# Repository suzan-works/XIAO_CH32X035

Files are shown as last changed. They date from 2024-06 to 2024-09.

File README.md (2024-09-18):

# サポートページ：CH32X035搭載XIAOピン互換ボード Support page for CH32X035 XIAO-Compatible Board #XIAO_CH32X035
WCH CH32X035を搭載した小型のマイコンボードです。
Arduino IDEからプログラム可能で、USB PDシンクとして動作できます。

Tiny microcontroller board equipped with WCH CH32X035. 
It can be programmed from the Arduino IDE and functions as a USB PD sink.  

## CH32X035搭載XIAOピン互換ボード CH32X035 XIAO-Compatible Board
WCH CH32X035搭載のUSB PD対応マイコンボードです。  
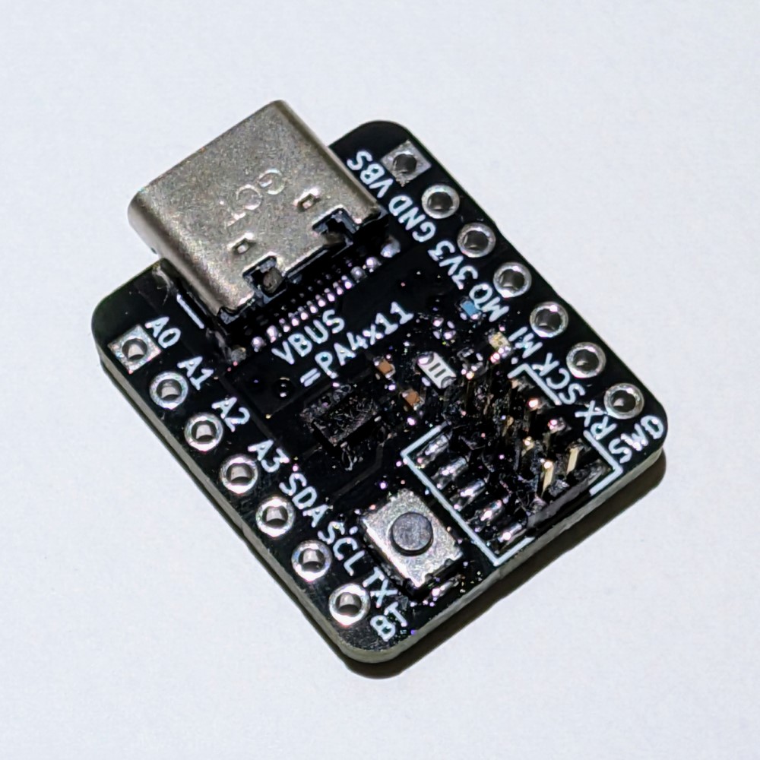
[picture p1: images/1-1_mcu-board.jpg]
  
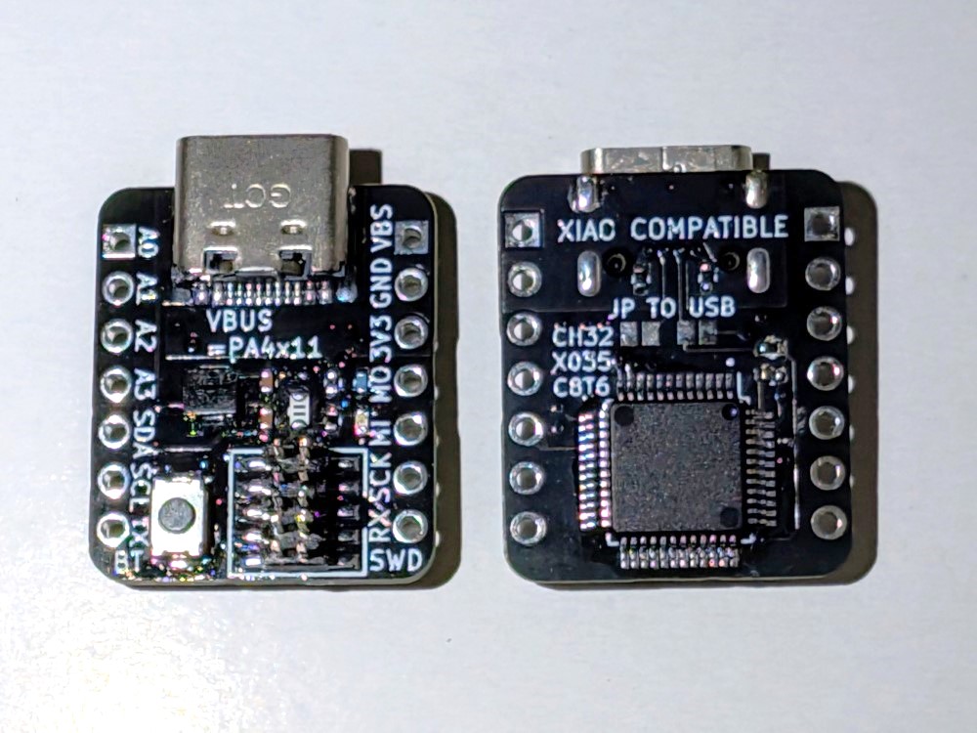
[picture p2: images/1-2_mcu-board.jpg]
  
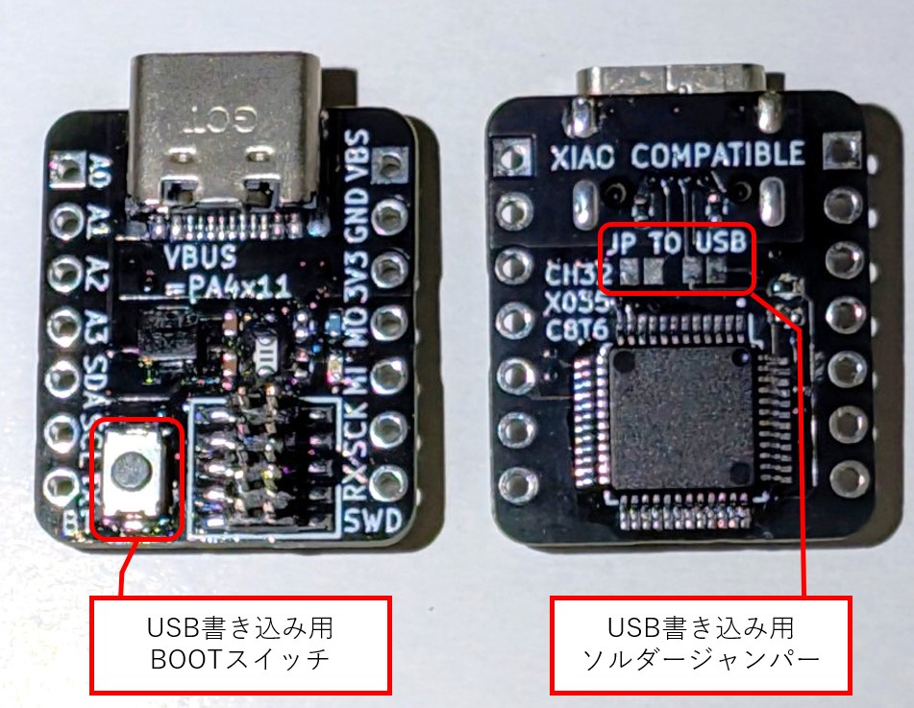
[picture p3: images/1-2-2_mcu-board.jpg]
  
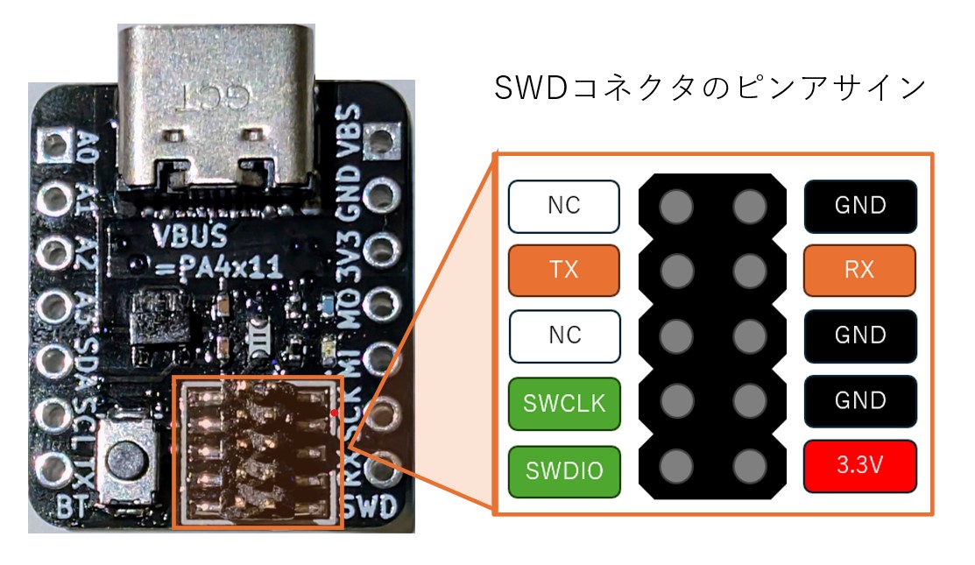
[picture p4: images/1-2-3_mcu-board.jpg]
  
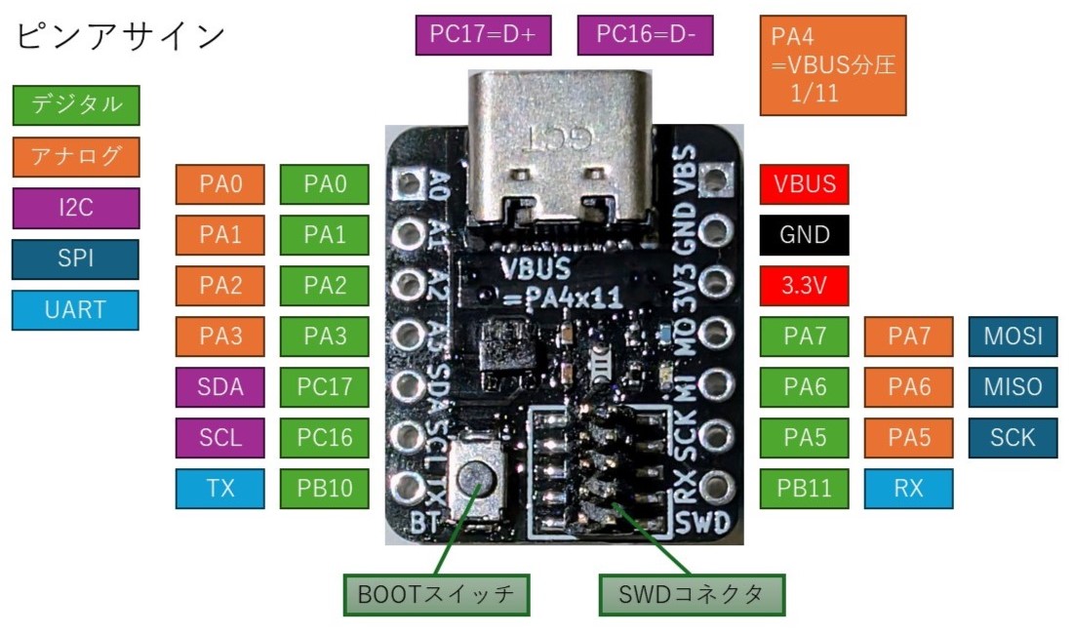
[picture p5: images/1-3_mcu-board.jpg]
  
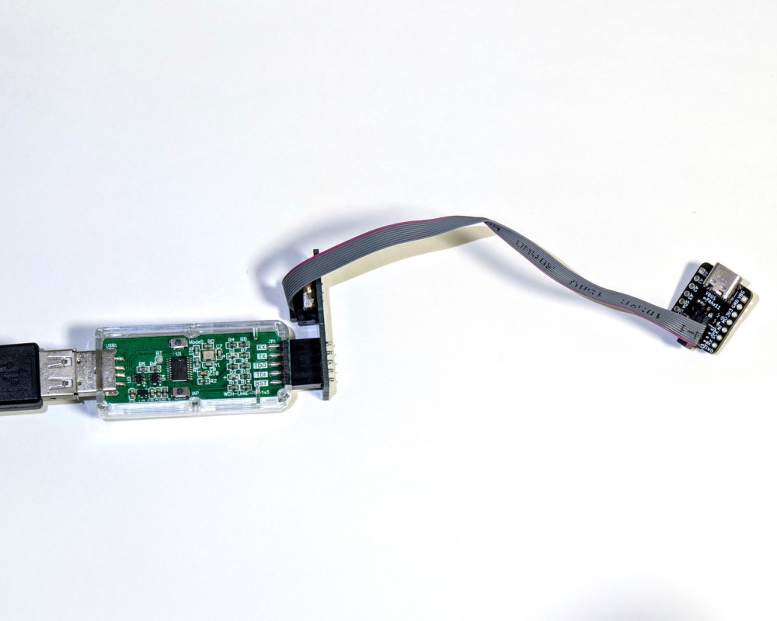
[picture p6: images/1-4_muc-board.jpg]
  
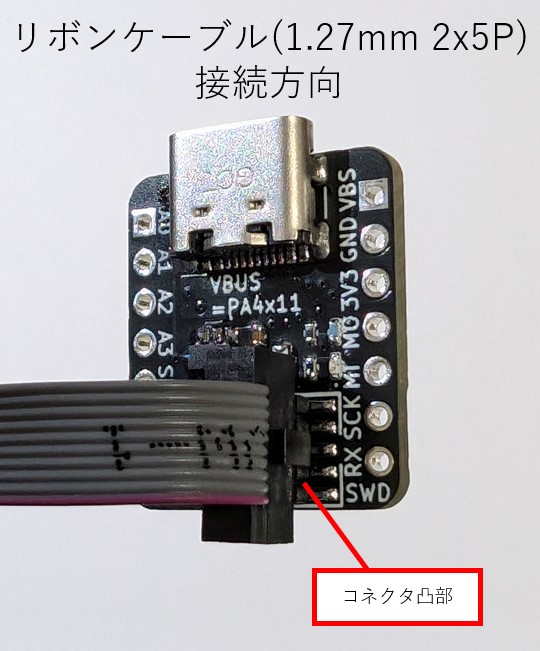
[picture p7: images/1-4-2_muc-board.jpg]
  
  
[回路図PDF](hardware/CH32X035_XIAO-Compatible_Board/CH32X035_XIAO-Compatible_Board.pdf)  
[回路図をブラウザで見る](https://kicanvas.org/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)  
[基板データをブラウザで見る](https://kicanvas.org/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)  
  
## SWD変換基板 SWD Converter Board
デバッガWCH-LinkEとマイコンボード上のコネクタ(1.27mm 10P)を接続するための変換基板です。  
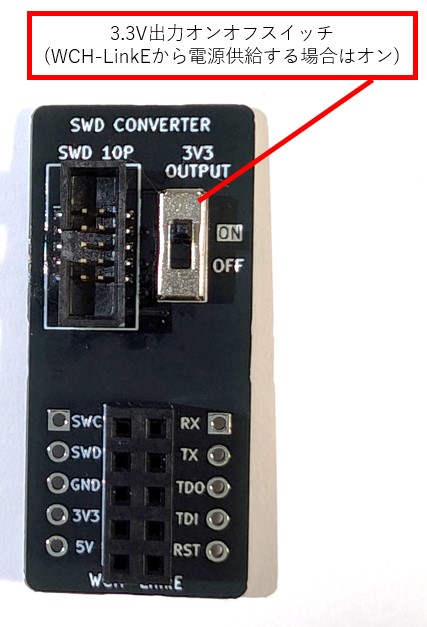
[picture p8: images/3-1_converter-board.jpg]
  
  
[回路図PDF](hardware/SWD_Converter_Board/SWD_Converter_Board.pdf)  
[回路図をブラウザで見る](https://kicanvas.org/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)  
[基板データをブラウザで見る](https://kicanvas.org/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)  
  
## VBUSスイッチアドオンボード VBUS Switch Add-on Board
マイコンボードからVBUS出力のオンオフを切り替えられるアドオンボードです。
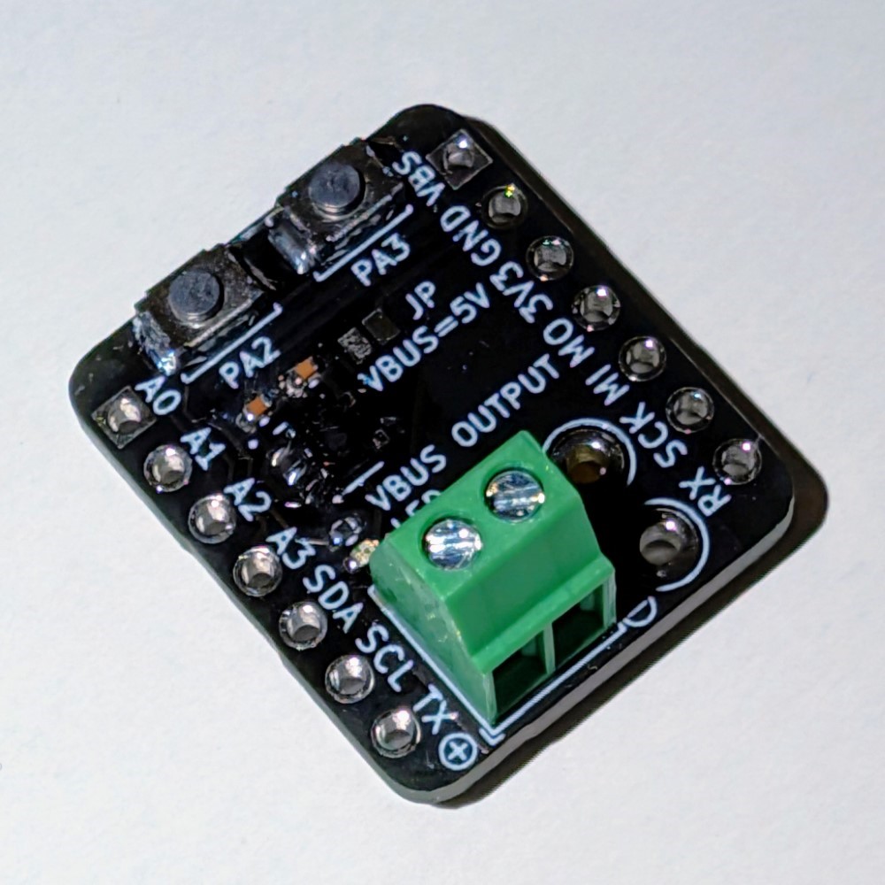
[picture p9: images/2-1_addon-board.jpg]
  
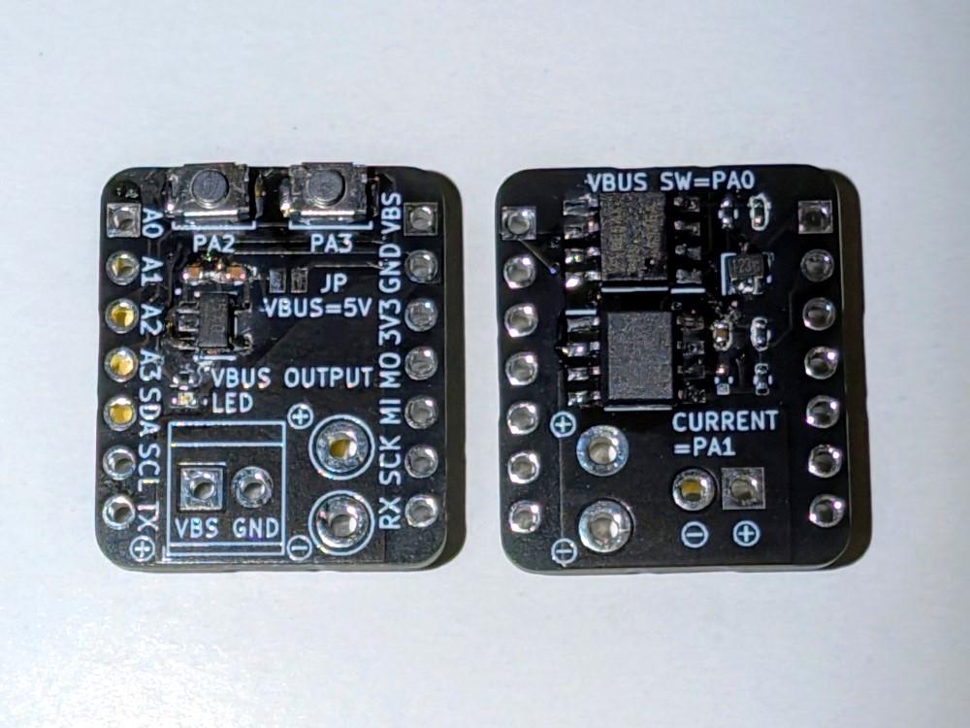
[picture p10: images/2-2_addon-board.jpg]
  
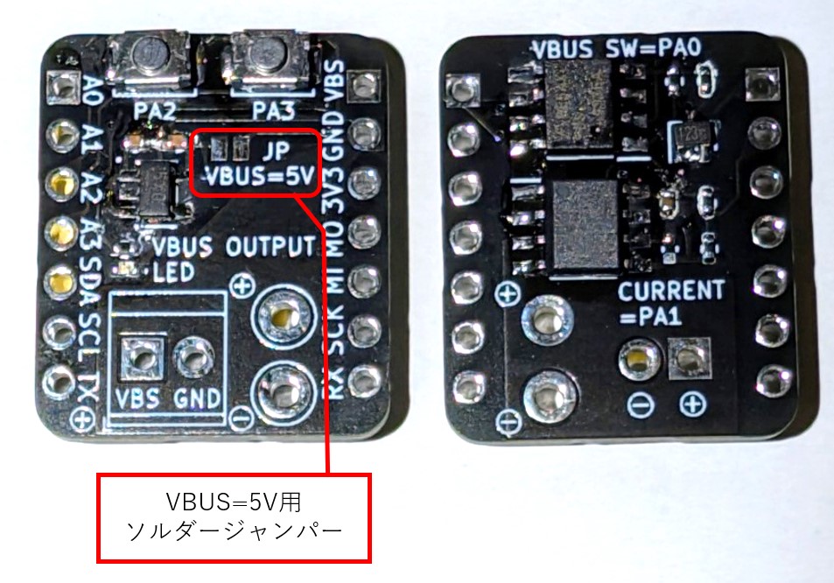
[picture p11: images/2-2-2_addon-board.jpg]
  
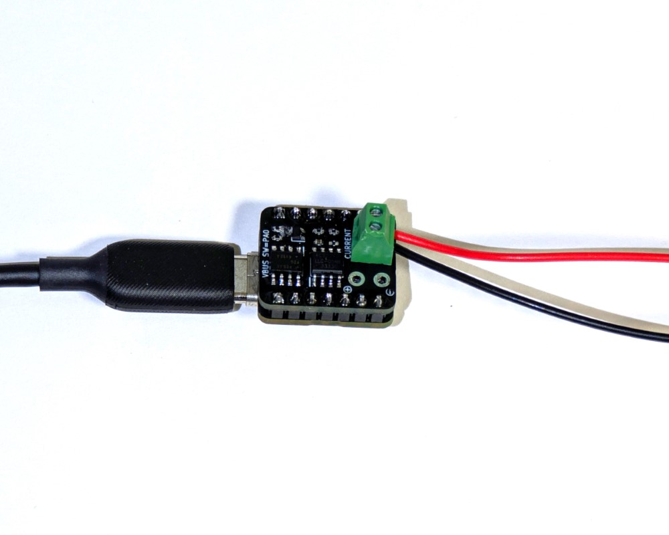
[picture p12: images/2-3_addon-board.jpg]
  
  
[回路図PDF](hardware/VBUS_Switch_Addon_Board/VBUS_Switch_Addon_Board.pdf)  
[回路図をブラウザで見る](https://kicanvas.org/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)  
[基板データをブラウザで見る](https://kicanvas.org/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)  
  
## 導入手順
### Arduino IDE
WCH arduino_core_ch32をインストールすることで、Arduino IDEで開発ができます。  
https://github.com/openwch/arduino_core_ch32  
ボード設定でCH32X035を選択してください。
### 初期ファームウェア
[PreInstalledFirmware.ino](software/examples/PreInstalledFirmware/PreInstalledFirmware.ino) : 5秒ごとにUSB PDの電圧を切り替えます。テスター等でVBUS-GND間の電圧をご確認ください。

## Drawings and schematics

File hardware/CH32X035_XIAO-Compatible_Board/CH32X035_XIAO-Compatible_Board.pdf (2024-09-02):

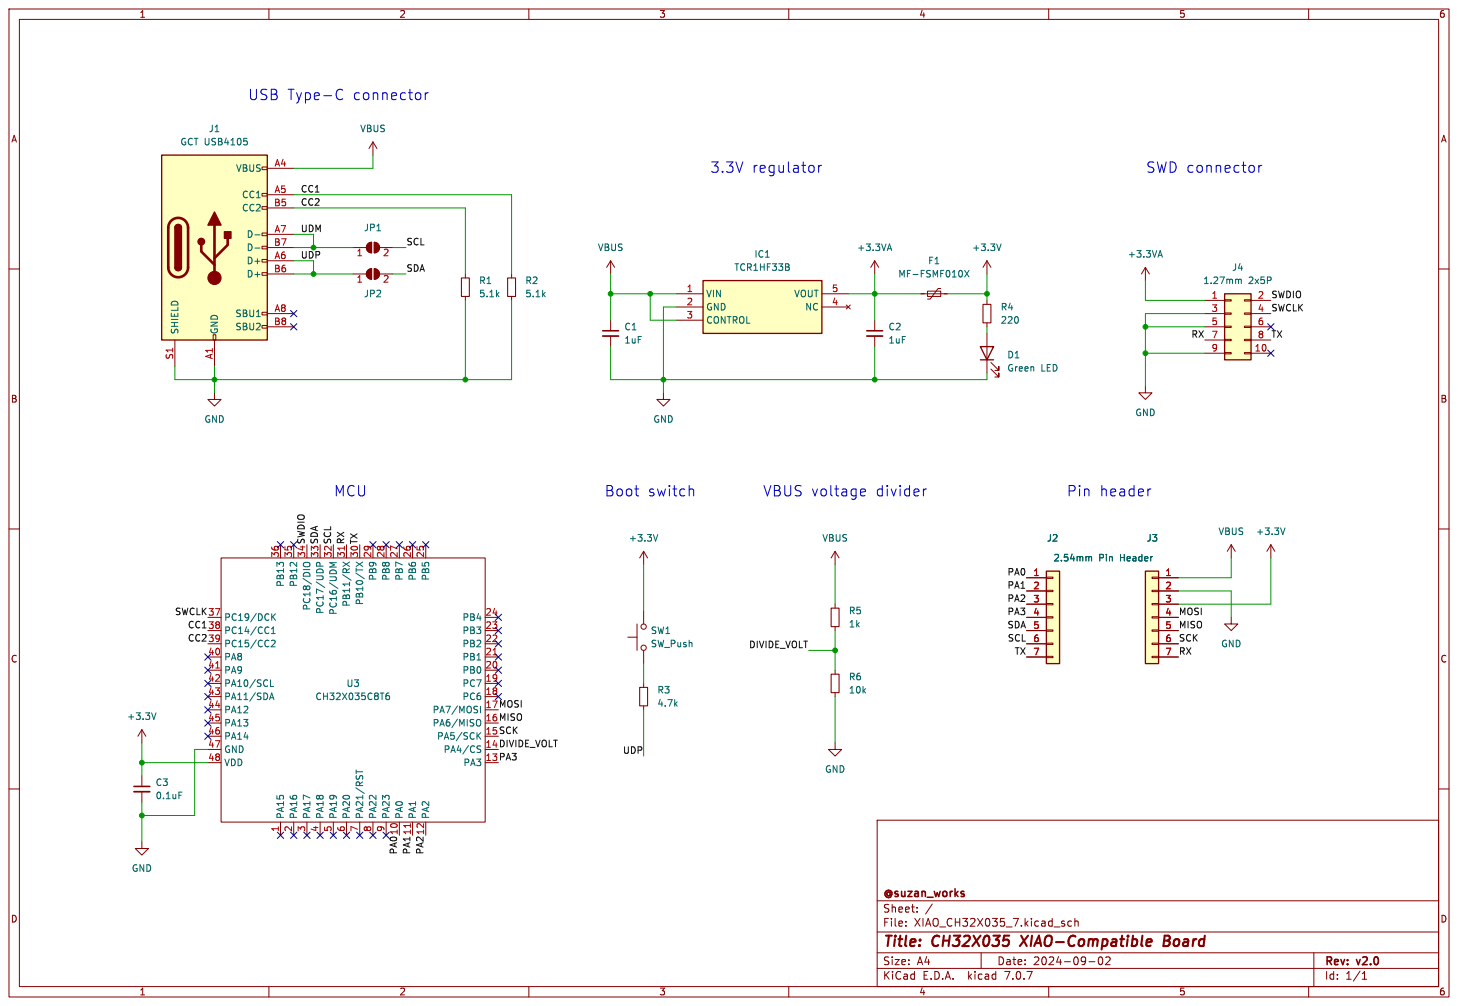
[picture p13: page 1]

3 PB10/TX 30 PB11/RX 31 PC16/UDM 32 PC17/UDP 33 PC18/DIO 34 PB12 35 PB13 36 PC19/DCK 37 PC14/CC1 38 PC15/CC2 39 PA18

4 PA8 40 PA9 41 PA10/SCL 42 PA11/SDA 43 PA12 44 PA13 45 PA14 46 GND 47 VDD 48 PA19

1 PA0 10 PA1 11 PA2 12 PA3 13 PA4/CS 14 PA5/SCK 15 PA6/MISO 16 PA7/MOSI 17 PC6 18 PC7 19 PA16

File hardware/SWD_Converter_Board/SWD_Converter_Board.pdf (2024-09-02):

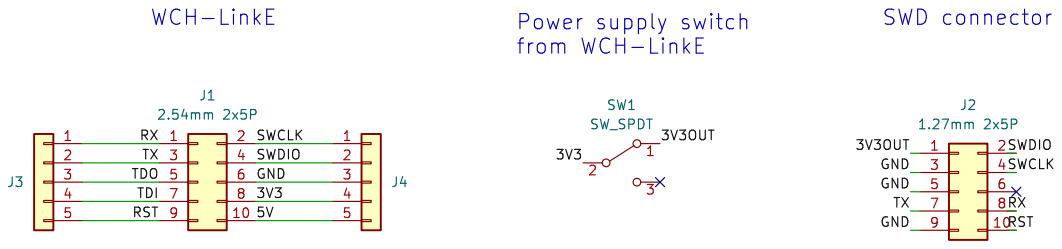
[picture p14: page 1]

4 7 | 8 4
5 9 | 10 5V 5

Id: 1/1 Title: SWD Converter Board

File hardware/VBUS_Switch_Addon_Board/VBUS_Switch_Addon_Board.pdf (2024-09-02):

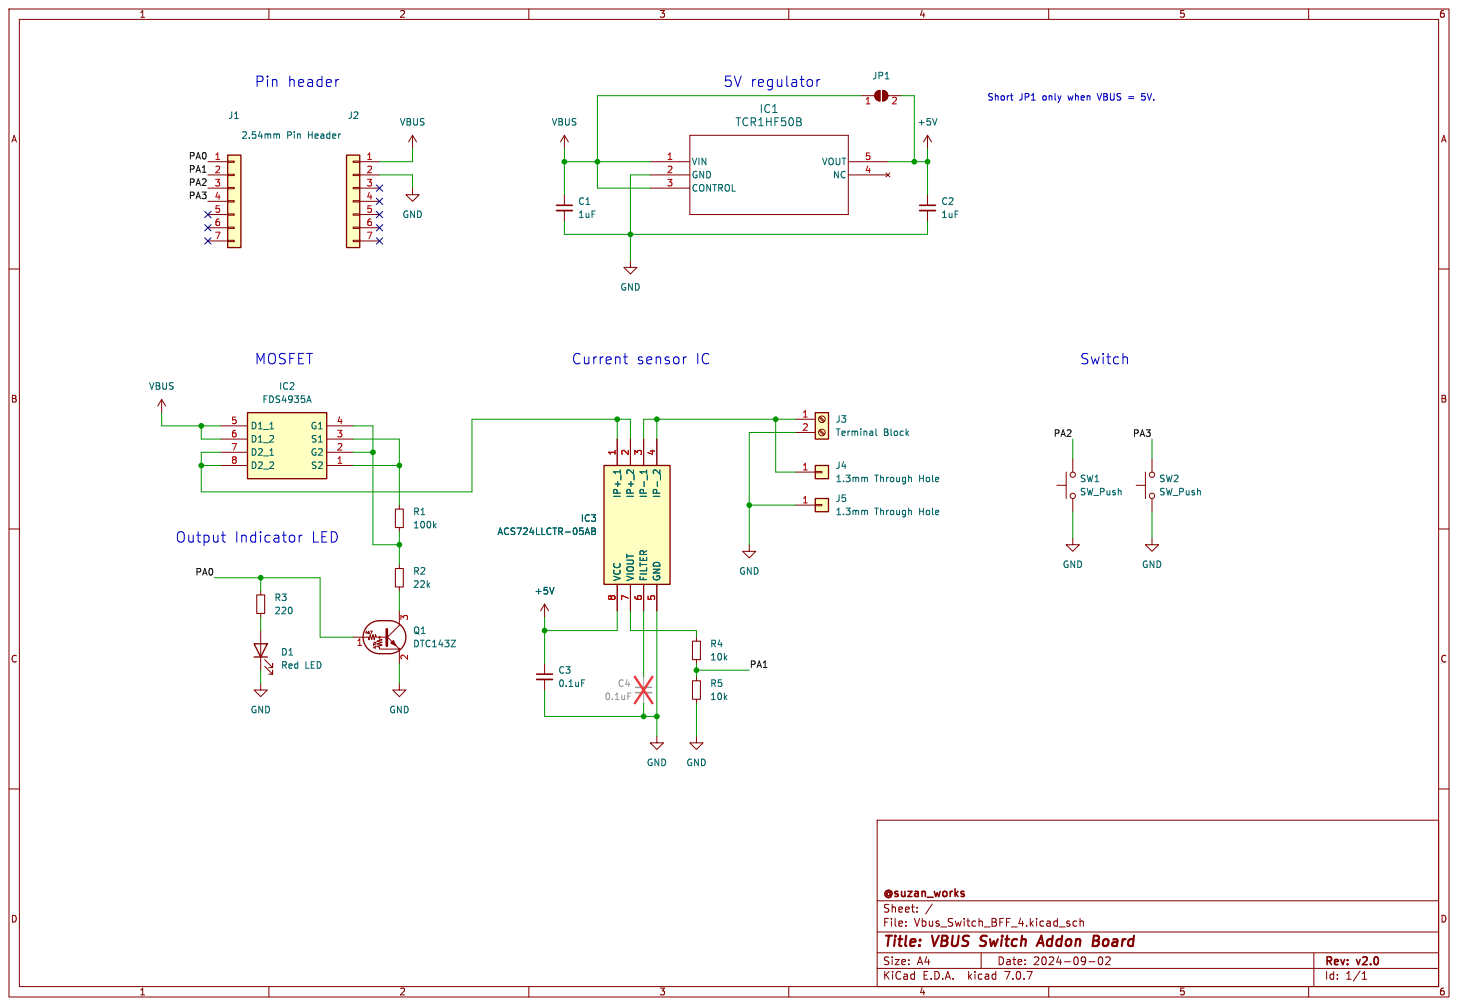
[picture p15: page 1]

Short JP1 only when VBUS = 5V.

1.3mm Through Hole GND GND

Id: 1/1 Title: VBUS Switch Addon Board

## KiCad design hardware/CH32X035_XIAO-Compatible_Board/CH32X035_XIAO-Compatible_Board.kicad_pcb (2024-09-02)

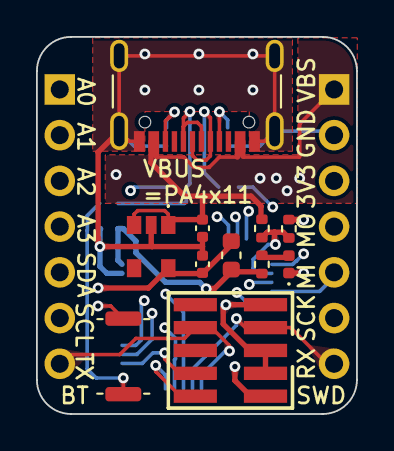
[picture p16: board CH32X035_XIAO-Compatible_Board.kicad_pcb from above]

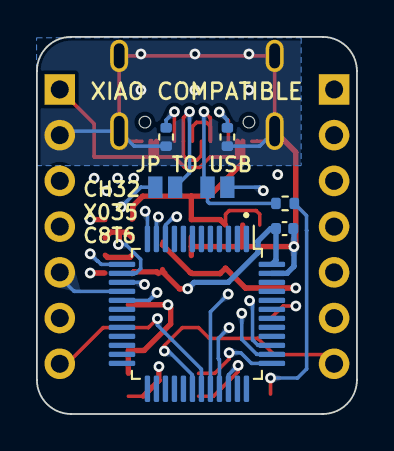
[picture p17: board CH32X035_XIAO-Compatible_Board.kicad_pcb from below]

Board: 4 copper layers, 17.8 x 21.0 mm, 20 parts (9 on the bottom side), 24 nets.

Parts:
C1, C2: C_Small; C_0402_1005Metric
C3: 0.1uF; C_0402_1005Metric
D1: LED; LED_0402_1005Metric
F1: Polyfuse_Small; Fuse_0603_1608Metric
IC1: TCR1HF33B; TCR1HF33BLMCT
J1: GCT USB4105; USB_C_Receptacle_GCT_USB4105-xx-A_16P_TopMnt_Horizontal
J2, J3: Conn_01x07; PinHeader_1x07_P2.54mm_Vertical
J4: Conn_02x05_Odd_Even; PinHeader_2x05_P1.27mm_Vertical_SMD
JP1, JP2: SolderJumper_2_Open; SolderJumper-2_P1.3mm_Open_Pad0.8x1.2mm
R1, R2: 5.1k; R_0402_1005Metric
R3: 4.7k; R_0402_1005Metric
R4, R5, R6: R_Small; R_0402_1005Metric
SW1: SW_Push; SW_Push_SPST_NO_Alps_SKRK
U3: CH32X035C8T6; LQFP-48_7x7mm_P0.5mm

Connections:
+3.3V: C3.1, F1.2, J3.3, R4.1, SW1.2, U3.48 (VDD)
+3.3VA: C2.1, F1.1, IC1.5 (VOUT), J4.1
/CC1: J1.A5 (CC1), R2.1, U3.38 (PC14/CC1)
/CC2: J1.B5 (CC2), R1.1, U3.39 (PC15/CC2)
/DIVIDE_VOLT: R5.2, R6.1, U3.14 (PA4/CS)
/MISO: J3.5, U3.16 (PA6/MISO)
/MOSI: J3.4, U3.17 (PA7/MOSI)
/PA0: J2.1, U3.10 (PA0)
/PA1: J2.2, U3.11 (PA1)
/PA2: J2.3, U3.12 (PA2)
/PA3: J2.4, U3.13 (PA3)
/RX: J3.7, J4.7, U3.31 (PB11/RX)
/SCK: J3.6, U3.15 (PA5/SCK)
/SCL: J2.6, JP1.2 (B), U3.32 (PC16/UDM)
/SDA: J2.5, JP2.2 (B), U3.33 (PC17/UDP)
/SWCLK: J4.4, U3.37 (PC19/DCK)
/SWDIO: J4.2, U3.34 (PC18/DIO)
/TX: J2.7, J4.8, U3.30 (PB10/TX)
/UDM: J1.A7 (D-), J1.B7 (D-), JP1.1 (A)
/UDP: J1.A6 (D+), J1.B6 (D+), JP2.1 (A), R3.2
GND: C1.2, C2.2, C3.2, D1.1 (K), IC1.2 (GND), J1.A1 (GND), J1.A12 (GND), J1.B1 (GND), J1.B12 (GND), J1.S1 (SHIELD), J3.2, J4.3, J4.5, J4.9, R1.2, R2.2, R6.2, U3.47 (GND)
unnamed: D1.2 (A), R4.2
unnamed: R3.1, SW1.1
VBUS: C1.1, IC1.1 (VIN), IC1.3 (CONTROL), J1.A4 (VBUS), J1.A9 (VBUS), J1.B4 (VBUS), J1.B9 (VBUS), J3.1, R5.1

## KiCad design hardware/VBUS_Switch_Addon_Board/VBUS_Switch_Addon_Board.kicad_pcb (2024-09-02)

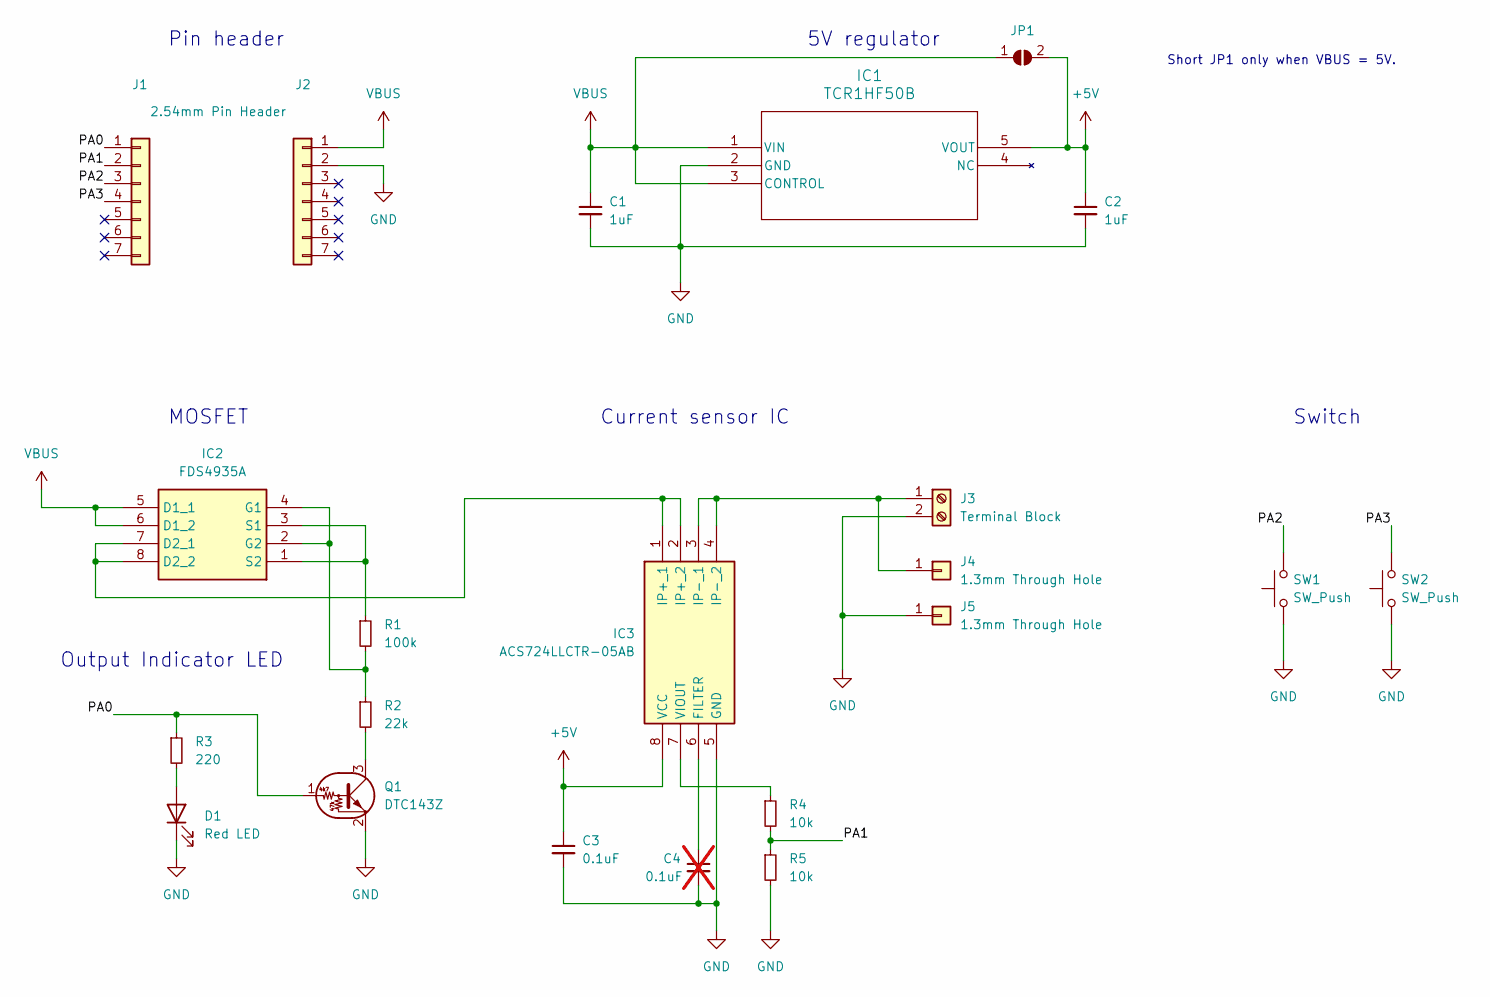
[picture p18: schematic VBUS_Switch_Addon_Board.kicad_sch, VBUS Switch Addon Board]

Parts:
C1, C2: 1uF; C_0402_1005Metric
C3: 0.1uF; C_0402_1005Metric
C4: 0.1uF; C_0402_1005Metric; not fitted
D1: Red LED; LED_0402_1005Metric
IC1: TCR1HF50B
IC2: FDS4935A; Manufacturer_Part_Number FDS4935A
IC3: ACS724LLCTR-05AB; Manufacturer_Part_Number ACS724LLCTR-05AB-T
J1: 2.54mm Pin Header; PinHeader_1x07_P2.54mm_Vertical
J2: Conn_01x07; PinHeader_1x07_P2.54mm_Vertical
J3: Terminal Block; TerminalBlock_TE_282834-2_1x02_P2.54mm_Horizontal
J4, J5: 1.3mm Through Hole; Pin_D1.3mm_L11.0mm
JP1: SolderJumper_2_Open; SolderJumper-2_P1.3mm_Open_Pad0.8x1.2mm
Q1: DTC143Z; SOT-323_SC-70
R1: 100k; R_0402_1005Metric
R2: 22k; R_0402_1005Metric
R3: 220; R_0402_1005Metric
R4, R5: 10k; R_0402_1005Metric
SW1, SW2: SW_Push; SW_Push_SPST_NO_Alps_SKRK

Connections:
+5V: C2.1, C3.1, IC1.5 (VOUT), IC3.8 (VCC), JP1.2 (B)
/PA0: J1.1, Q1.1 (B), R3.1
/PA1: J1.2, R4.2, R5.1
/PA2: J1.3, SW1.2
/PA3: J1.4, SW2.2
GND: C1.2, C2.2, C3.2, C4.2, D1.1 (K), IC1.2 (GND), IC3.5 (GND), J2.2, J3.2, J5.1, Q1.2 (E), R5.2, SW1.1, SW2.1
unnamed: D1.2 (A), R3.2
unnamed: IC2.7 (D2_1), IC2.8 (D2_2), IC3.1 (IP+_1), IC3.2 (IP+_2)
unnamed: IC2.2 (G2), IC2.4 (G1), R1.2, R2.1
unnamed: IC2.1 (S2), IC2.3 (S1), R1.1
unnamed: C4.1, IC3.6 (FILTER)
unnamed: IC3.3 (IP-_1), IC3.4 (IP-_2), J3.1, J4.1
unnamed: IC3.7 (VIOUT), R4.1
unnamed: Q1.3 (C), R2.2
VBUS: C1.1, IC1.1 (VIN), IC1.3 (CONTROL), IC2.5 (D1_1), IC2.6 (D1_2), J2.1, JP1.1 (A)

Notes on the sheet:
Output Indicator LED
Switch
5V regulator
Current sensor IC
MOSFET
Pin header
Short JP1 only when VBUS = 5V.

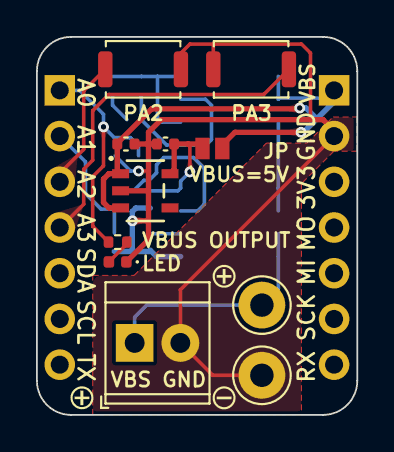
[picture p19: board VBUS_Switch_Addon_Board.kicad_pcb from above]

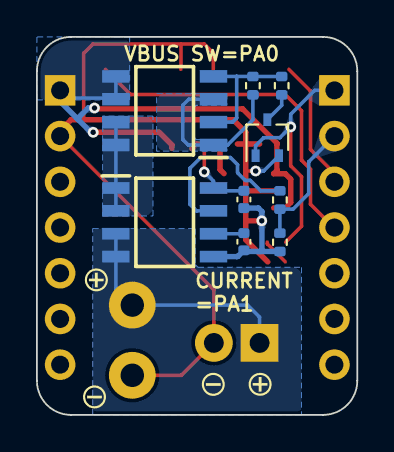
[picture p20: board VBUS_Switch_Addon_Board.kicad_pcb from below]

Board: 2 copper layers, 17.8 x 21.0 mm, 22 parts (11 on the bottom side), 15 nets.

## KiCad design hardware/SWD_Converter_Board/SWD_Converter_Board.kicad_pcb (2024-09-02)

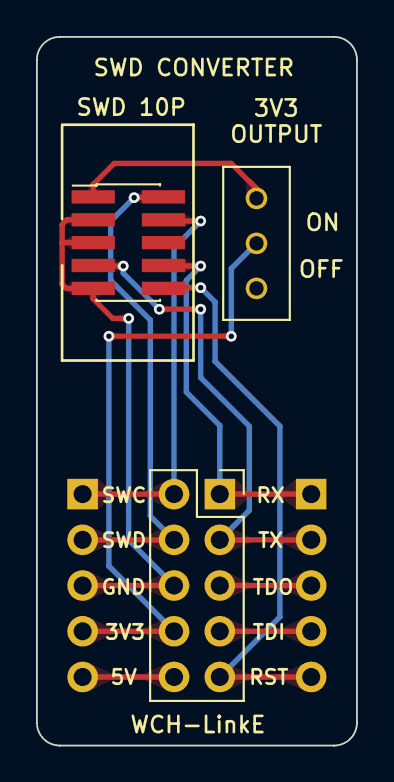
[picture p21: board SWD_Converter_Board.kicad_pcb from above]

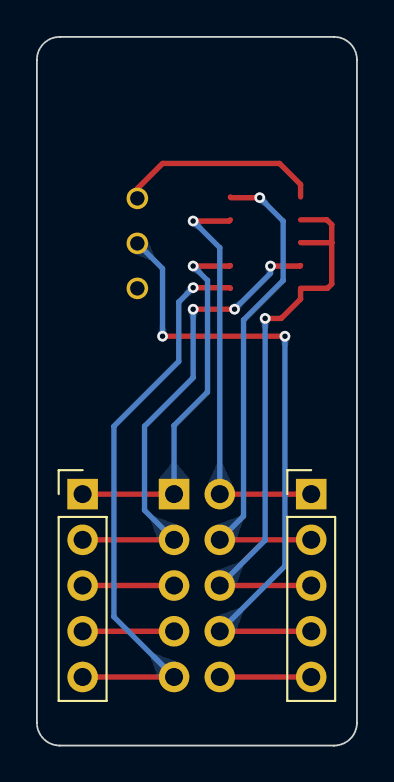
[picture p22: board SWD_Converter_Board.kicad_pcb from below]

Board: 2 copper layers, 17.8 x 39.4 mm, 5 parts (2 on the bottom side), 11 nets.

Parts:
J1: Conn_02x05_Odd_Even; PinSocket_2x05_P2.54mm_Vertical
J2: Conn_02x05_Odd_Even; PinHeader_2x05_P1.27mm_Vertical_SMD
J3, J4: Conn_01x05; PinHeader_1x05_P2.54mm_Vertical
SW1: SW_SPDT; SS-12D00G3

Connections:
/3V3: J1.8, J4.4, SW1.2 (B)
/3V3OUT: J2.1, SW1.1 (A)
/5V: J1.10, J4.5
/GND: J1.6, J2.3, J2.5, J2.9, J4.3
/RST: J1.9, J2.10, J3.5
/RX: J1.1, J2.8, J3.1
/SWCLK: J1.2, J2.4, J4.1
/SWDIO: J1.4, J2.2, J4.2
/TDI: J1.7, J3.4
/TDO: J1.5, J3.3
/TX: J1.3, J2.7, J3.2

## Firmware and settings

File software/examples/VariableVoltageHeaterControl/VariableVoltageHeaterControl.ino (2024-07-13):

#include <usbpd_def.h>
#include <usbpd_sink.h>
#include <Wire.h>
#include <Adafruit_GFX.h>
#include <Adafruit_SSD1306.h>
#include <SPI.h>
#include "Adafruit_MAX31855.h"

uint8_t setVoltage = REQUEST_5v;  // 初期設定のリクエスト電圧は5V

#define SCREEN_WIDTH 128
#define SCREEN_HEIGHT 64
#define OLED_RESET     -1
#define SCREEN_ADDRESS 0x3C
Adafruit_SSD1306 display(SCREEN_WIDTH, SCREEN_HEIGHT, &Wire, OLED_RESET);

#define MAXDO   PA6
#define MAXCS   PB11 // RX
#define MAXCLK  PA5
Adafruit_MAX31855 thermocouple(MAXCLK, MAXCS, MAXDO);

const int vbusControlPin = PA0;
const int divideVoltPin = PA4;

float volt = 5;
float temp = 25;
int degCDisplay = 25;
bool outputState = 0;
double degC = 25;
const double tempA = 60;
const double tempB = 50;

void setup() {
  // Serial.begin(115200);

  // USB PDシンクの初期化
  usbpd_sink_init();
  
  // OLEDディスプレイの初期化と起動表示
  display.begin(SSD1306_SWITCHCAPVCC, SCREEN_ADDRESS);
  display.clearDisplay();
  display.setTextSize(1);
  display.setTextColor(SSD1306_WHITE);
  display.setCursor(35, 35);
  display.println("XIAO");
  display.setCursor(35, 50);
  display.println("CH32X035");
  display.display();

  pinMode(vbusControlPin, OUTPUT); // VBUS制御ピンを出力に設定
  pinMode(divideVoltPin, INPUT);   // 分圧ピンを入力に設定

  // 熱電対アンプモジュールの初期化
  if (!thermocouple.begin()) {
    // Serial.println("ERROR.");
    while (1) delay(10);
  }

  delay(2000);
}

void loop() {
  // ヒーター温度の読み取り
  degC = thermocouple.readCelsius();
  if (isnan(degC)) {
    uint8_t e = thermocouple.readError();
  }
  if ((degC > 10)&&(degC <100)) {
    degCDisplay = (int) degC;
  }

  // VBUS電圧の読み取り
  int voltRead = analogRead(divideVoltPin);
  float voltCalc = (float) voltRead;
  voltCalc = ((voltCalc * 11 * 3.3) / 4095);  // 読み取った値を実際の電圧に変換
  volt = voltCalc;

  // ヒーター温度から動作を判断
  if (degC >= tempA) {
    outputState = 0;
  } else {
    if (degC >= tempB) {
      setVoltage = REQUEST_9v;
    } else {
      setVoltage = REQUEST_15v;
    }
    // USB PDシンクが準備完了か確認し、リクエスト電圧を設定
    if (usbpd_sink_get_ready()) {
      usbpd_sink_set_request_fixed_voltage(setVoltage);
    }
    delay(500);
    if (setVoltage == REQUEST_9v) {
      if ((volt > 8)&&(volt < 10)) {
        outputState = 1;
      } else {
        outputState = 0;
      }
    }
    if (setVoltage == REQUEST_15v) {
      if ((volt > 14)&&(volt < 16)) {
        outputState = 1;
      } else {
        outputState = 0;
      }
    }
  }
  digitalWrite(vbusControlPin, outputState);

  // OLEDディスプレイの表示
  display.clearDisplay();
  display.setCursor(35, 35);
  display.print(volt);
  display.println("V");
  display.setCursor(35, 50);
  display.print(degCDisplay);
  display.println("C");
  if (outputState) {
    display.setCursor(64, 50);
    display.println("ON");
  } else {
    display.setCursor(64, 50);
    display.println("OFF");
  }
  display.display();

  delay(500);
}

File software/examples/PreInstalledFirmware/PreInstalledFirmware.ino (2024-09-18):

// ファームウェア情報
// バージョン: 1.0
// ファイル名: PreInstalledFirmware.ino
// 対象ボード: CH32X035搭載XIAOピン互換ボード (CH32X035 XIAO-Compatible Board)
// 設計者: GitHubアカウント suzan-works , Xアカウント @suzan_works

// 動作概要
// 5秒ごとにUSB PD（Power Delivery）の電圧を切り替えます。
// PA4ピンからアナログ電圧を読み取り、その値をシリアル通信で送信します。

// 参考
// https://github.com/openwch/arduino_core_ch32/tree/main/libraries/USBPD_SINK

#include <usbpd_def.h>
#include <usbpd_sink.h>

// ピンアサイン
//const int pin = PA0; // "A0"
//const int pin = PA1; // "A1"
//const int pin = PA2; // "A2"
//const int pin = PA3; // "A3"
//const int pin = PC17; // "SDA"
//const int pin = PC16; // "SCL"
//const int pin = PB10; // "TX"
//const int pin = PB11; // "RX"
//const int pin = PA5; // "SCK"
//const int pin = PA6; // "MI"
//const int pin = PA7; // "MO"

// アナログ入力ピンの定義（VBUS電圧の読み取り用）
// VBUSは電圧分圧回路（10k:1k）を介してPA4に接続されています。 VBUS = PA4 x 11
const int pin = PA4;

// PD電圧要求を管理するための変数
int pdIndex = 0;
int setVoltage = REQUEST_5v;

void setup()
{
  Serial.begin(115200);
  pinMode(pin, INPUT);
  usbpd_sink_init(); // USB PDシンク機能を初期化
  delay(1000);
}

void loop()
{
  // 現在のpdIndexに基づいて要求する電圧を設定
  switch(pdIndex)
  {
    case 0:
      setVoltage = REQUEST_5v;
      break;
    case 1:
      setVoltage = REQUEST_9v;
      break;
    case 2:
      setVoltage = REQUEST_12v;
      break;
    case 3:
      setVoltage = REQUEST_15v;
      break;
    case 4:
      setVoltage = REQUEST_20v;
      break;
    default:
      setVoltage = REQUEST_5v; // デフォルトで5Vを要求
      break;
  }
  Serial.println(pdIndex); // 現在のpdIndexをシリアルモニタに出力

  // USB PDシンクが準備完了か確認してから新しい電圧を要求
  if(usbpd_sink_get_ready())
  {
    usbpd_sink_set_request_fixed_voltage(setVoltage);
  }
  delay(1000); // 電圧変更の反映を待つために1秒待機

  // PA4からアナログ値を読み取り
  int value = analogRead(pin);
  Serial.println(value);
  delay(4000); // 次の電圧変更まで4秒待機（合計で5秒間隔）

  // pdIndexをインクリメントし、0〜4の範囲でループ
  pdIndex = (pdIndex + 1) % 5;
}

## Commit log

2024-05-09 回路図と外観写真を追加
2024-06-24 フォルダ構成変更
2024-06-24 回路図と写真を追加
2024-06-24 回路図を追加
2024-06-24 YouTubeリンクを追記
2024-06-27 KiCadファイル追加
    [XIAO_CH32X035.kicad_pcb, XIAO_CH32X035.kicad_sch]
2024-06-27 KiCanvas表示を追加
2024-06-27 READMEにKiCanvas表示を追加
2024-07-13 examplesを追加
2024-07-13 READMEを追記
2024-07-14 READMEにデモ動画リンクを追加
2024-09-02 サポートページ用の回路図・基板設計データの変更
    [CH32X035_XIAO-Compatible_Board.kicad_pcb, CH32X035_XIAO-Compatible_Board.kicad_sch, SWD_Converter_Board.kicad_pcb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]
2024-09-16 サポートページとして構成変更
    [MINI_OLED_BFF.kicad_pcb, MINI_OLED_BFF.kicad_sch]
2024-09-17 サポートページの拡充
2024-09-17 初期ファームウェア追加
2024-09-18 初期ファームウェアにコメント追記
2024-09-18 README追記
